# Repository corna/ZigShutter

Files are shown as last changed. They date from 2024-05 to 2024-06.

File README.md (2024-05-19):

# ZigShutter

ZigShutter is a platform for the control of window shutters and IAS.

It features:
 * ZigBee connectivity through a nRF52840 module
 * AC power supply
 * Control of two outputs with SSR, to control the two directions of a window shutter motor
 * Two inputs for window opening sensors
 * Eight GPIOs

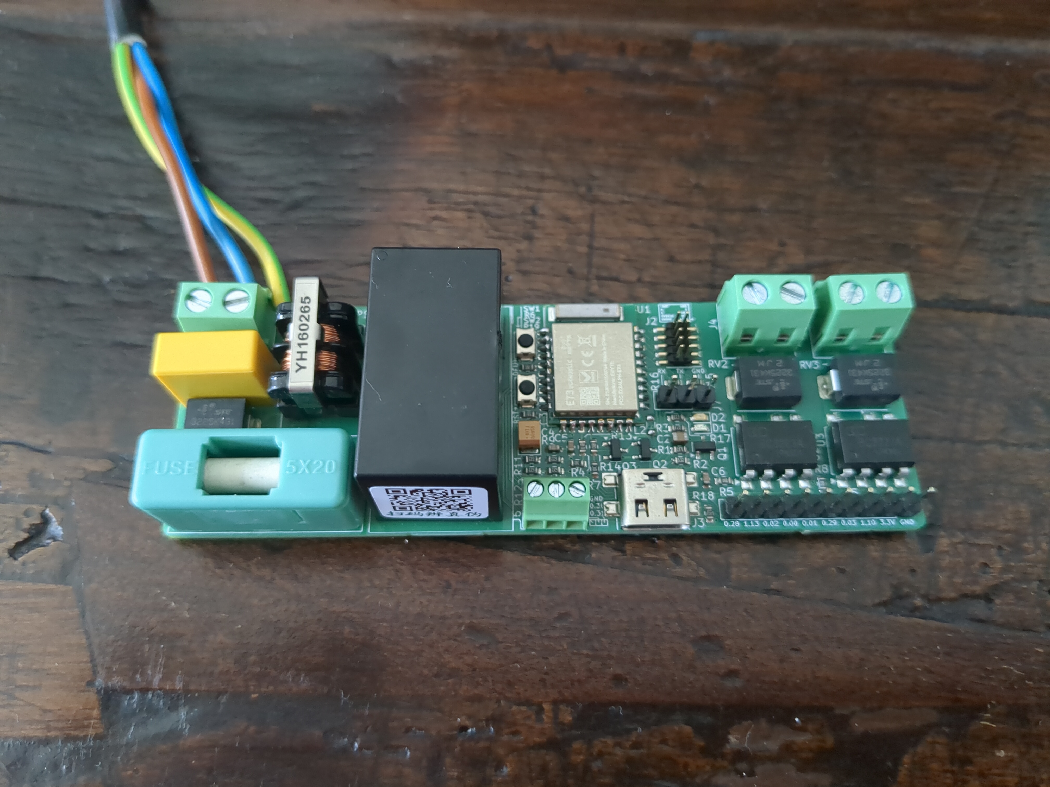
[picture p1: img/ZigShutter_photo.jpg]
ZigShutter photo

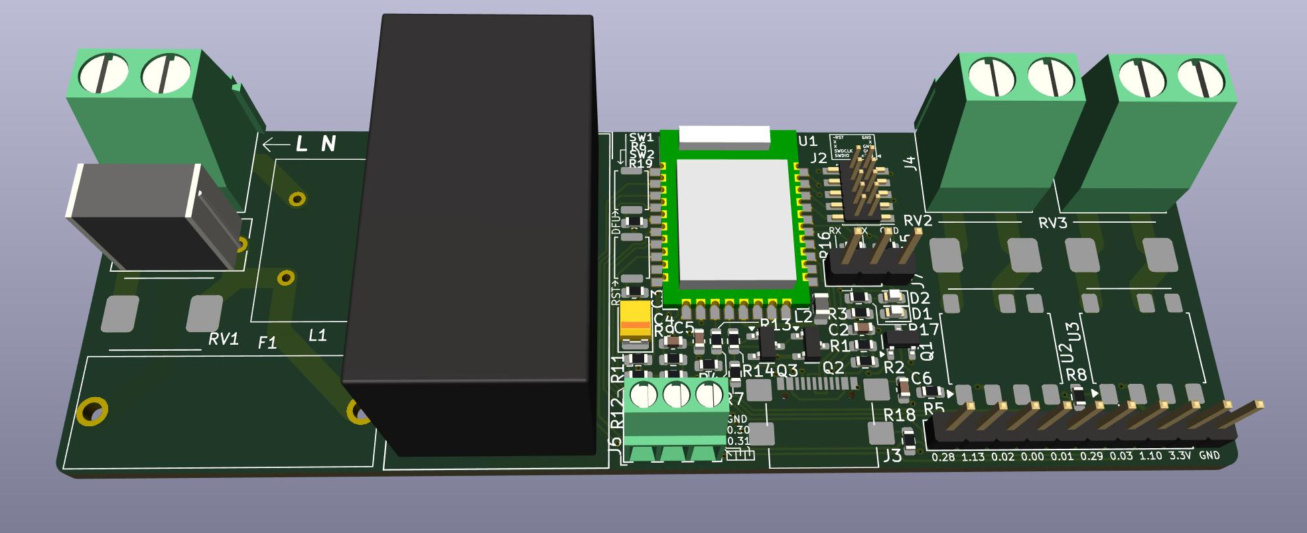
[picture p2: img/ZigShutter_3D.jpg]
ZigShutter 3D render


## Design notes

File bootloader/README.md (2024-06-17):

# ZigShutter bootloader

This platform uses the [Adafruit nRF52 Bootloader](https://github.com/adafruit/Adafruit_nRF52_Bootloader/)
as bootloader.

This folder contains the files needed to build the bootloader for this
platform. To do so, clone the [Adafruit nRF52 Bootloader](https://github.com/adafruit/Adafruit_nRF52_Bootloader/)
and copy the `ZigShutter` folder into the bootloader's `src/boards` one, then
follow the build and flash instructions specifying `BOARD=ZigShutter`.

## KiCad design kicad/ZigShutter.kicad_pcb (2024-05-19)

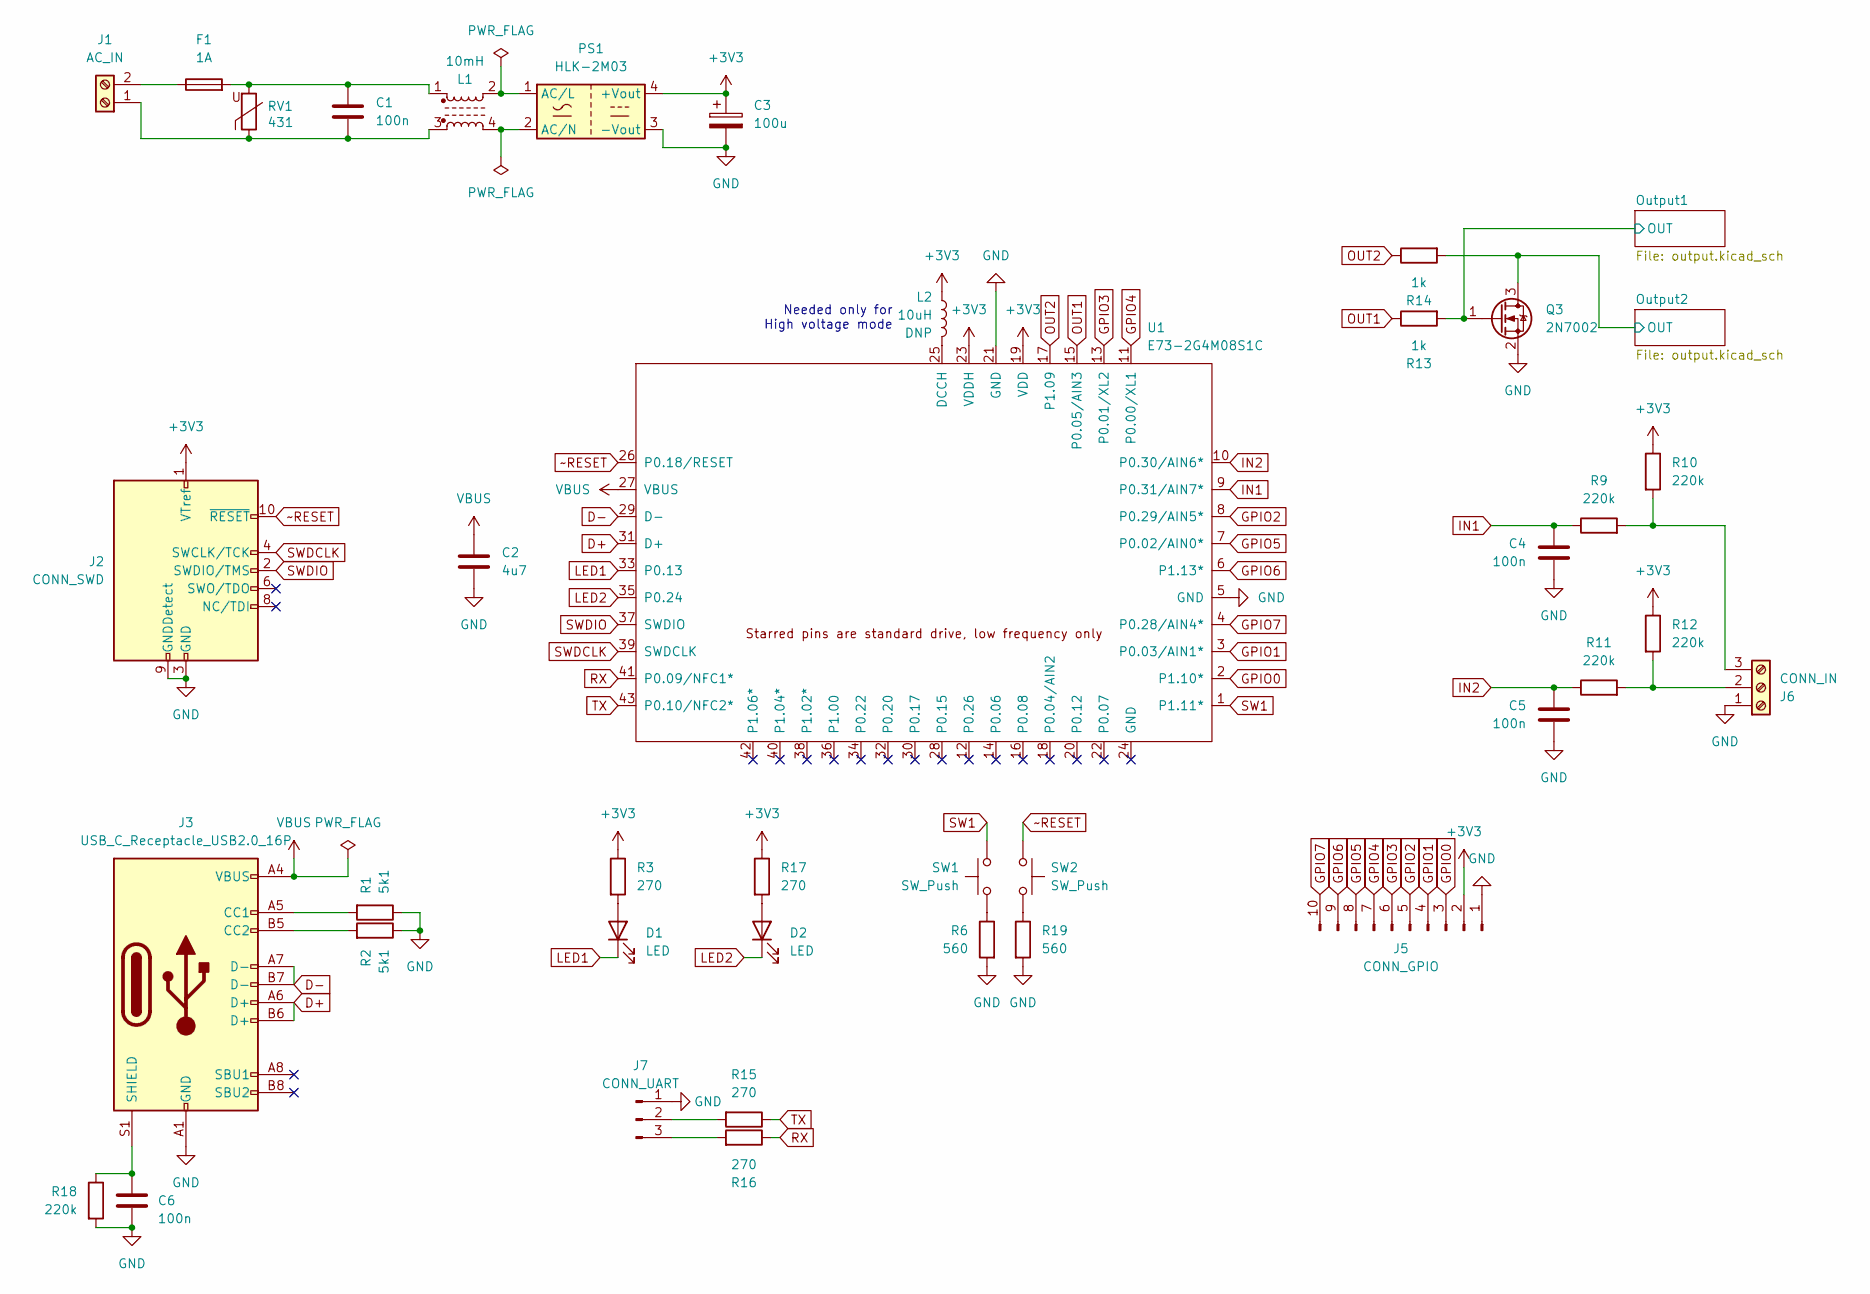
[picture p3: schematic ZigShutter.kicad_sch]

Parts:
C1: 100n; C_Rect_L11.5mm_W5.0mm_P10.00mm_MKT
C2: 4u7; C_0603_1608Metric
C3: 100u; CP_EIA-3528-21_Kemet-B
C4, C5, C6: 100n; C_0603_1608Metric
D1, D2: LED; LED_0603_1608Metric
F1: 1A; XFCN_PTF-77
J1: AC_IN; TerminalBlock_Phoenix_MKDS-1,5-2_1x02_P5.00mm_Horizontal
J2: CONN_SWD; PinHeader_2x05_P1.27mm_Vertical_SMD
J3: USB_C_Receptacle_USB2.0_16P; USB_C_Receptacle_XKB_U262_161N_4BSS73_T
J5: CONN_GPIO; PinHeader_1x10_P2.54mm_Vertical
J6: CONN_IN; TerminalBlock_Phoenix_MPT-0,5-3-2.54_1x03_P2.54mm_Horizontal
J7: CONN_UART; PinHeader_1x03_P2.54mm_Vertical
L1: 10mH; UU9.8
L2: 10uH; L_0805_2012Metric
PS1: HLK-2M03; Converter_ACDC_Hi-Link_HLK-2Mxx
Q3: 2N7002; SOT-23
R1, R2: 5k1; R_0603_1608Metric
R3, R15, R16, R17: 270; R_0603_1608Metric
R6, R19: 560; R_0603_1608Metric
R9, R10, R11, R12, R18: 220k; R_0603_1608Metric
R13, R14: 1k; R_0603_1608Metric
RV1: 431; RV_3225
SW1, SW2: SW_Push; SW_Push_SPST_NO_Alps_SKRK
U1: E73-2G4M08S1C

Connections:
+3V3: C3.1, J2.1 (VTref), J5.2, L2.1, PS1.4 (+Vout), R3.1, R10.1, R12.1, R17.1, U1.19 (VDD), U1.23 (VDDH); also elsewhere on the board
/Output1/OUT: Q3.1 (G), R13.2; also elsewhere on the board
/Output2/OUT: Q3.3 (D), R14.2; also elsewhere on the board
D+: J3.A6 (D+), J3.B6 (D+), U1.31 (D+)
D-: J3.A7 (D-), J3.B7 (D-), U1.29 (D-)
GND: C2.2, C3.2, C4.2, C5.2, C6.2, J2.3 (GND), J2.5 (GND), J2.9 (GNDDetect), J3.A1 (GND), J3.A12 (GND), J3.B1 (GND), J3.B12 (GND), J5.1, J6.1, J7.1, PS1.3 (-Vout), Q3.2 (S), R1.1, R2.1, R6.2, R18.2, R19.2, U1.5 (GND), U1.21 (GND); also elsewhere on the board
GPIO0: J5.3, U1.2 (P1.10*)
GPIO1: J5.4, U1.3 (P0.03/AIN1*)
GPIO2: J5.5, U1.8 (P0.29/AIN5*)
GPIO3: J5.6, U1.13 (P0.01/XL2)
GPIO4: J5.7, U1.11 (P0.00/XL1)
GPIO5: J5.8, U1.7 (P0.02/AIN0*)
GPIO6: J5.9, U1.6 (P1.13*)
GPIO7: J5.10, U1.4 (P0.28/AIN4*)
IN1: C4.1, R9.1, U1.9 (P0.31/AIN7*)
IN2: C5.1, R11.1, U1.10 (P0.30/AIN6*)
LED1: D1.1 (K), U1.33 (P0.13)
LED2: D2.1 (K), U1.35 (P0.24)
unnamed: C1.1, F1.2, L1.1, RV1.2
unnamed: D1.2 (A), R3.2
unnamed: D2.2 (A), R17.2
unnamed: C1.2, J1.1, L1.3, RV1.1
unnamed: F1.1, J1.2
unnamed: J3.A5 (CC1), R1.2
unnamed: J3.B5 (CC2), R2.2
unnamed: C6.1, J3.S1 (SHIELD), R18.1
unnamed: J6.2, R11.2, R12.2
unnamed: J6.3, R9.2, R10.2
unnamed: J7.2, R15.2
unnamed: J7.3, R16.2
unnamed: L1.2, PS1.1 (AC/L)
unnamed: L1.4, PS1.2 (AC/N)
unnamed: R6.1, SW1.2
unnamed: R19.1, SW2.2
unnamed: L2.2, U1.25 (DCCH)
OUT1: R13.1, U1.15 (P0.05/AIN3)
OUT2: R14.1, U1.17 (P1.09)
RX: R16.1, U1.41 (P0.09/NFC1*)
SW1: SW1.1, U1.1 (P1.11*)
SWDCLK: J2.4 (SWCLK/TCK), U1.39 (SWDCLK)
SWDIO: J2.2 (SWDIO/TMS), U1.37 (SWDIO)
TX: R15.1, U1.43 (P0.10/NFC2*)
VBUS: C2.1, J3.A4 (VBUS), J3.A9 (VBUS), J3.B4 (VBUS), J3.B9 (VBUS), U1.27 (VBUS)
~RESET: J2.10 (~RESET), SW2.1, U1.26 (P0.18/RESET)

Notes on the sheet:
Needed only for High voltage mode

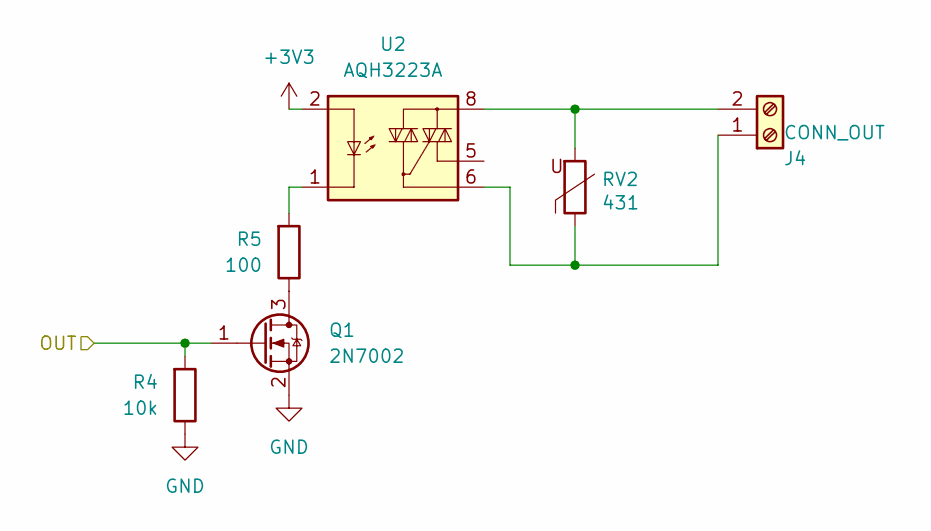
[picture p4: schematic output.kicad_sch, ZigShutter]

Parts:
J4: CONN_OUT; TerminalBlock_Phoenix_MKDS-1,5-2_1x02_P5.00mm_Horizontal
Q1: 2N7002; SOT-23
R4: 10k; R_0603_1608Metric
R5: 100; R_0603_1608Metric
RV2: 431; RV_3225
U2: AQH3223A; SSO-7-8_6.4x9.78mm_P2.54mm

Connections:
+3V3: U2.2; also elsewhere on the board
/Output1/OUT: Q1.1 (G), R4.2; also elsewhere on the board
GND: Q1.2 (S), R4.1; also elsewhere on the board
unnamed: J4.1, RV2.1, U2.6
unnamed: J4.2, RV2.2, U2.8
unnamed: Q1.3 (D), R5.1
unnamed: R5.2, U2.1, U2.3, U2.4

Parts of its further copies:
J8: CONN_OUT; TerminalBlock_Phoenix_MKDS-1,5-2_1x02_P5.00mm_Horizontal
Q2: 2N7002; SOT-23
R7: 10k; R_0603_1608Metric
R8: 100; R_0603_1608Metric
RV3: 431; RV_3225
U3: AQH3223A; SSO-7-8_6.4x9.78mm_P2.54mm

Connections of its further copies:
+3V3: U3.2; also elsewhere on the board
/Output2/OUT: Q2.1 (G), R7.2; also elsewhere on the board
GND: Q2.2 (S), R7.1; also elsewhere on the board
unnamed: J8.1, RV3.1, U3.6
unnamed: J8.2, RV3.2, U3.8
unnamed: Q2.3 (D), R8.1
unnamed: R8.2, U3.1, U3.3, U3.4

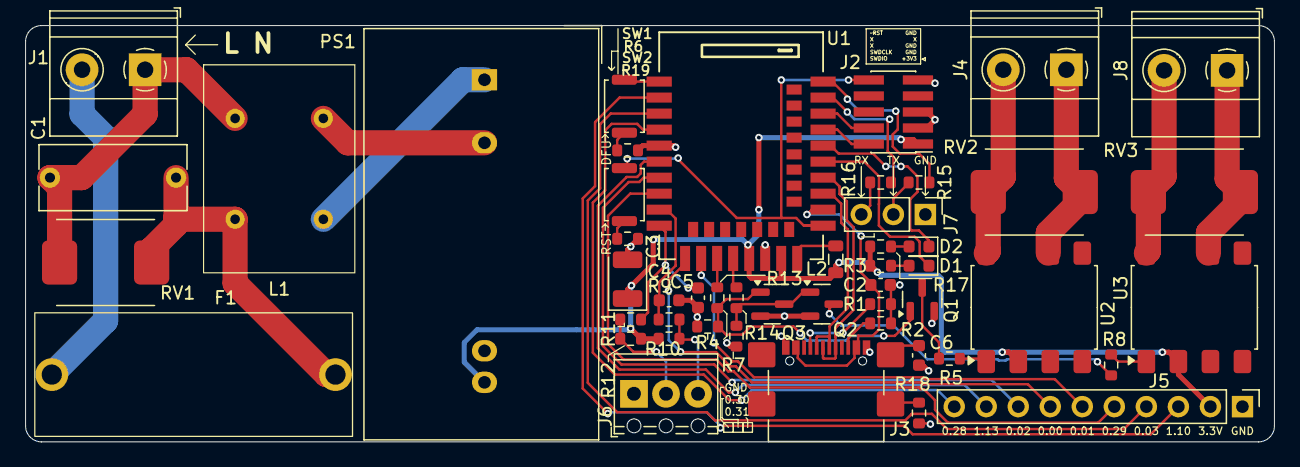
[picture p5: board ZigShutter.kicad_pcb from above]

Board: 2 copper layers, 99.1 x 33.0 mm, 50 parts (0 on the bottom side), 52 nets.

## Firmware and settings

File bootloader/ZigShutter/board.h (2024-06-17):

/*
 * The MIT License (MIT)
 *
 * Copyright (c) 2024 Nicola Corna <nicola@corna.info>
 *
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
 * THE SOFTWARE IS PROVIDED "AS IS", WITHOUT WARRANTY OF ANY KIND, EXPRESS OR
 * IMPLIED, INCLUDING BUT NOT LIMITED TO THE WARRANTIES OF MERCHANTABILITY,
 * FITNESS FOR A PARTICULAR PURPOSE AND NONINFRINGEMENT. IN NO EVENT SHALL THE
 * AUTHORS OR COPYRIGHT HOLDERS BE LIABLE FOR ANY CLAIM, DAMAGES OR OTHER
 * LIABILITY, WHETHER IN AN ACTION OF CONTRACT, TORT OR OTHERWISE, ARISING FROM,
 * OUT OF OR IN CONNECTION WITH THE SOFTWARE OR THE USE OR OTHER DEALINGS IN
 * THE SOFTWARE.
 */

#ifndef _ZIGSHUTTER_H
#define _ZIGSHUTTER_H

#define _PINNUM(port, pin)    ((port)*32 + (pin))

// Inductor is present on DCC pin, enable DCDC 1
#define ENABLE_DCDC_1 1

/*------------------------------------------------------------------*/
/* LED
 *------------------------------------------------------------------*/
#define LEDS_NUMBER           2
#define LED_PRIMARY_PIN       _PINNUM(0, 13)
#define LED_SECONDARY_PIN     _PINNUM(0, 24)
#define LED_STATE_ON          0

/*------------------------------------------------------------------*/
/* BUTTON
 *------------------------------------------------------------------*/
#define BUTTONS_NUMBER    2
#define BUTTON_1          _PINNUM(1, 11)    // DFU button
#define BUTTON_2          _PINNUM(0, 28)    // GPIO7
#define BUTTON_PULL       NRF_GPIO_PIN_PULLUP

//--------------------------------------------------------------------+
// BLE OTA
//--------------------------------------------------------------------+
#define BLEDIS_MANUFACTURER  "Nicola Corna"
#define BLEDIS_MODEL         "ZigShutter"

//--------------------------------------------------------------------+
// USB
//--------------------------------------------------------------------+
#define USB_DESC_VID           0x239A
#define USB_DESC_UF2_PID       0x0029
#define USB_DESC_CDC_ONLY_PID  0x0029

#define UF2_PRODUCT_NAME  "nRF52840 ZigShutter"
#define UF2_BOARD_ID      "nRF52840-zigshutter"
#define UF2_INDEX_URL     "https://github.com/corna/ZigShutter"

#endif // _ZIGSHUTTER_H

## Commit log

2024-05-19 Add KiCad files
    [ZigShutter.kicad_pcb, ZigShutter.kicad_sch, input.kicad_sch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]
2024-06-17 Add Zephyr board definition files

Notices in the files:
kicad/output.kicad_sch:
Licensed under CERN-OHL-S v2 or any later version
